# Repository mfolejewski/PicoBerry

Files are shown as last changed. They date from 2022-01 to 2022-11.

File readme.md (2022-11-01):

# PicoBerry - miniature Raspberry Pi CM4 carrier board with full 40-pin GPIO header

## Description

PicoBerry is a tiny Raspberry Pi CM4 carrier board, which has technical specification, as following:
- USB-C for power supply (5VDC/3A),
- full 40-pin GPIO header for connecting HAT boards,
- 2x user LEDs (green/red),
- support only CM4 versions (with eMMC onboard, CM4 Lite are not supported),
- standard ACT/PWR LEDs,
- 2-layer PCB, 20x70mm,
- fully open source project (OSHW).

You can connect to the CM4 module standard HAT boards, such as LCD screens (with SPI or DPI interfaces), audio DAC boards, RS232/485 or CAN interfaces, and many more...

Here you can find:
- \photos: a few pictures of the assembled PCB boards and design
- \manufacturing files: all the production files for ordering PCB and assembly at JLCPCB (Gerber files, Pick & Place, BOM, etc.)
- \source files: source files in KiCad and Altium Designer format

## License

Project published as Open Source Hardware (OSHW) under CERN OHL v1.2 (Open Hardware Licence).



Project has been certified as Open Source Hardware by the Open Source Hardware Association (OSHWA).

UID is: PL000010

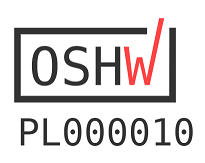
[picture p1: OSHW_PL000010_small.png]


https://certification.oshwa.org/pl000010.html

## Press release:

[Tom's Hardware](https://www.tomshardware.com/news/picoberry-raspberry-pi-4-compute-module-4-carrier-board)

[CNX Software](https://www.cnx-software.com/2022/10/24/miniature-raspberry-pi-cm4-carrier-board-usb-c-port-40-pin-gpio-header)

[NotebookCheck (EN)](https://www.notebookcheck.net/PicoBerry-Raspberry-Pi-Compute-Module-4-carrier-board-arrives-with-40-pin-GPIO-header-and-USB-Type-C-connectivity.664512.0.html)

[NotebookCheck (DE)](https://www.notebookcheck.com/PicoBerry-Besonders-kompaktes-Carrier-Board-fuer-das-Raspberry-Pi-CM4-ist-Open-Source.663859.0.html)

[NotebookCheck (PL)](https://www.notebookcheck.pl/PicoBerry-Raspberry-Plyta-nosna-Pi-Compute-Module-4-przybywa-z-40-pinowym-headerem-GPIO-i-lacznoscia-USB-Type-C.664668.0.html)

[Elektroda.pl (PL)](https://www.elektroda.pl/rtvforum/topic3928796.html)

[LinuxDevices](https://twitter.com/linuxdevices/status/1584419970343395328)

[Tux Machines](http://news.tuxmachines.org/n/2022/10/25/PicoBerry_Carrier_Board_for_the_Raspberry_Pi_CM_4_Build_one_for.shtml)

[Jeff Geerling](https://pipci.jeffgeerling.com/boards_cm/mirkos-picoberry-carrier-board.html)

[hackaday.io](https://hackaday.io/project/182747-picoberry-tiny-cm4-carrier-board)

...and much more:

https://twitter.com/search?q=picoberry&src=typed_query&f=live

https://www.google.com/search?q=picoberry+cm4&oq=picoberry+cm4

## Photos

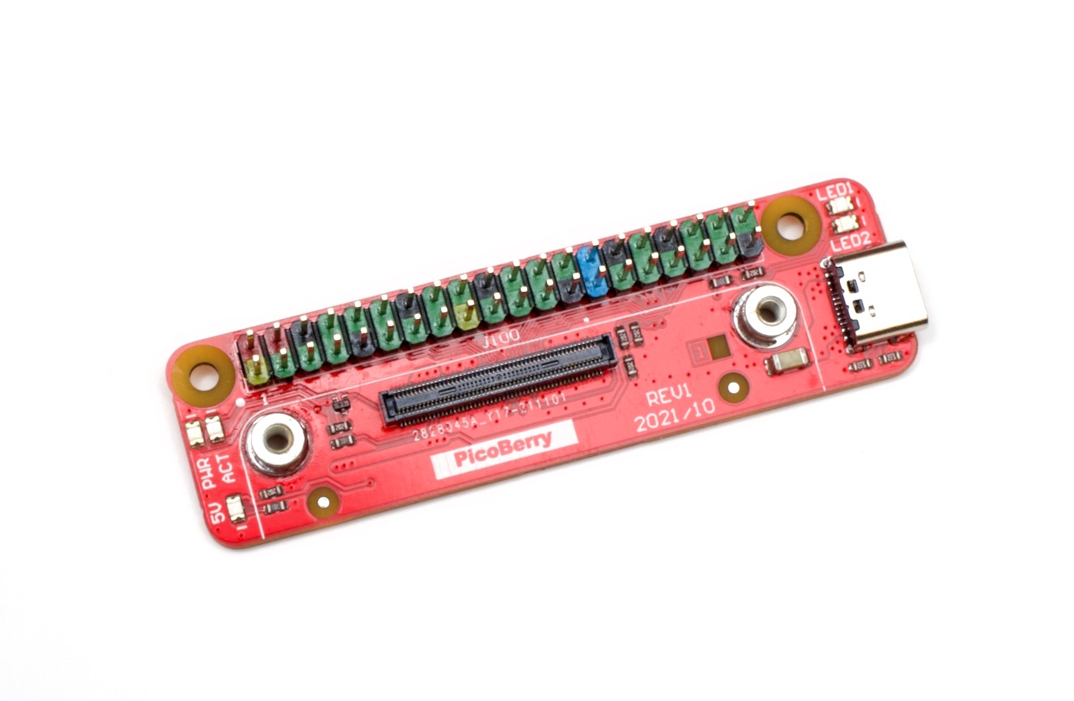
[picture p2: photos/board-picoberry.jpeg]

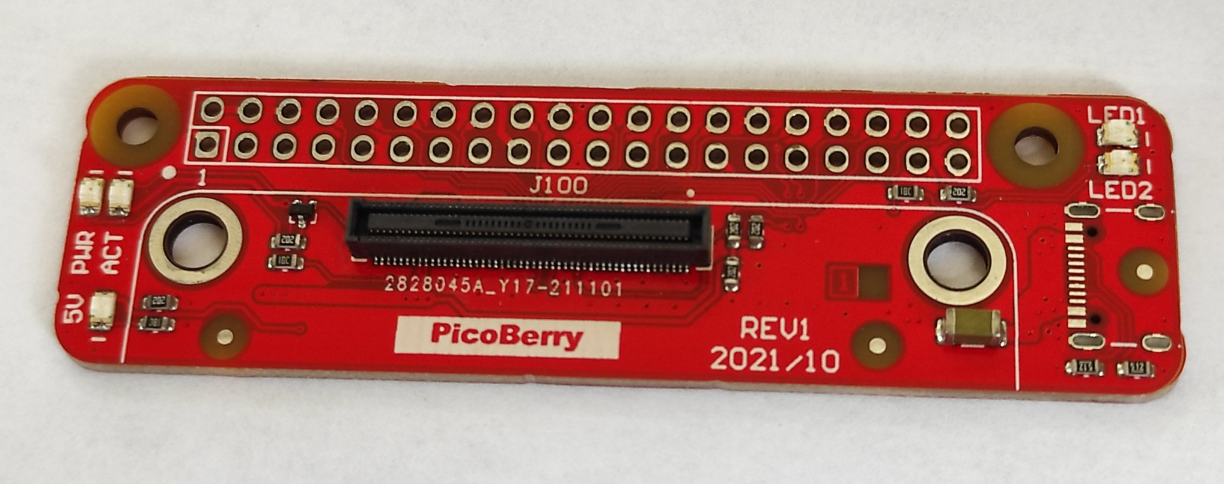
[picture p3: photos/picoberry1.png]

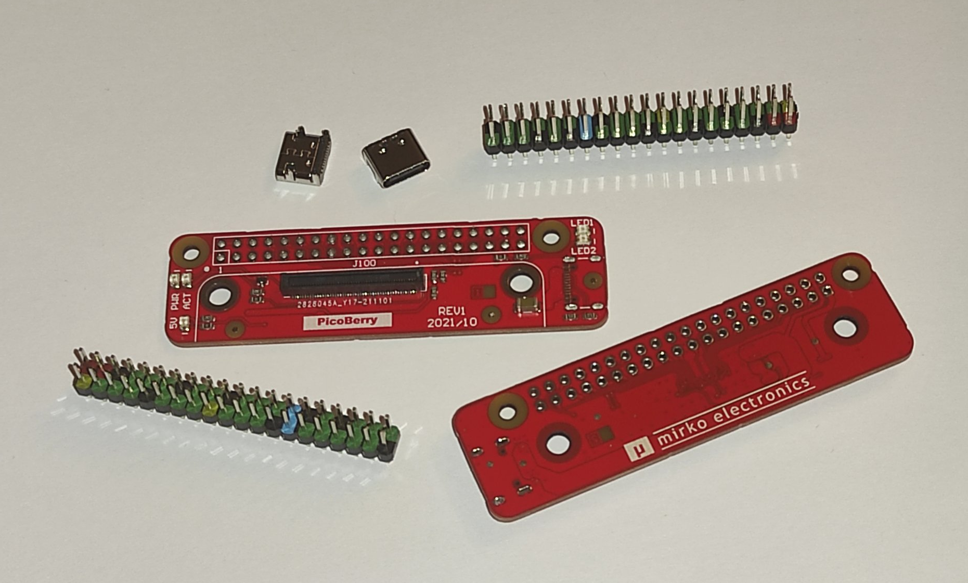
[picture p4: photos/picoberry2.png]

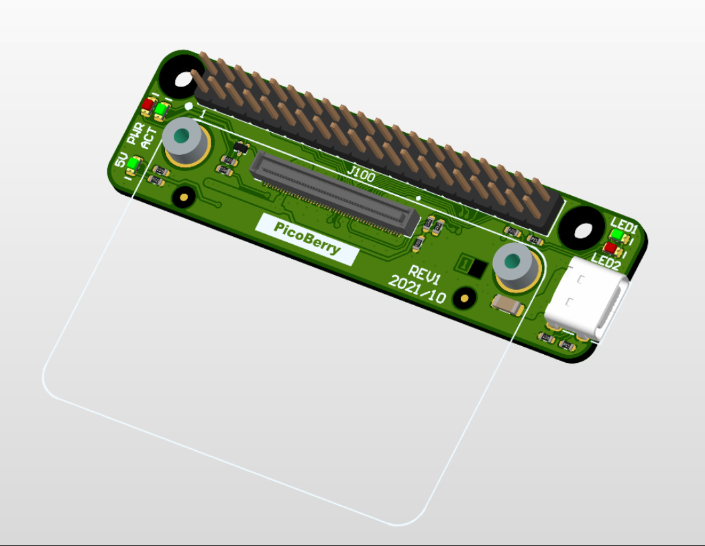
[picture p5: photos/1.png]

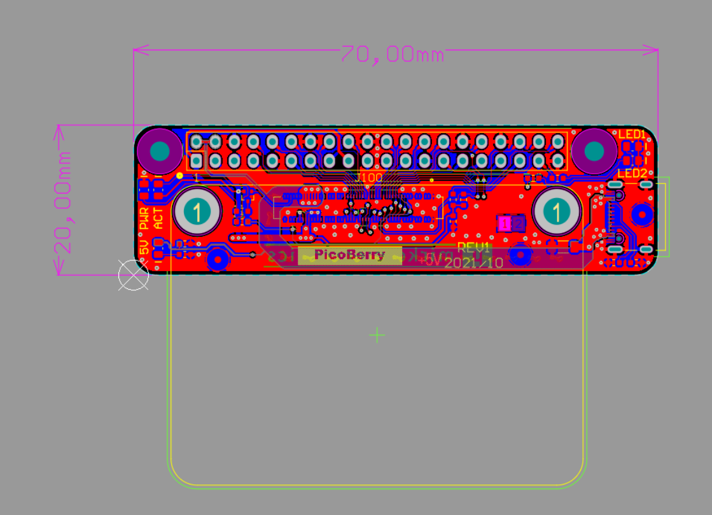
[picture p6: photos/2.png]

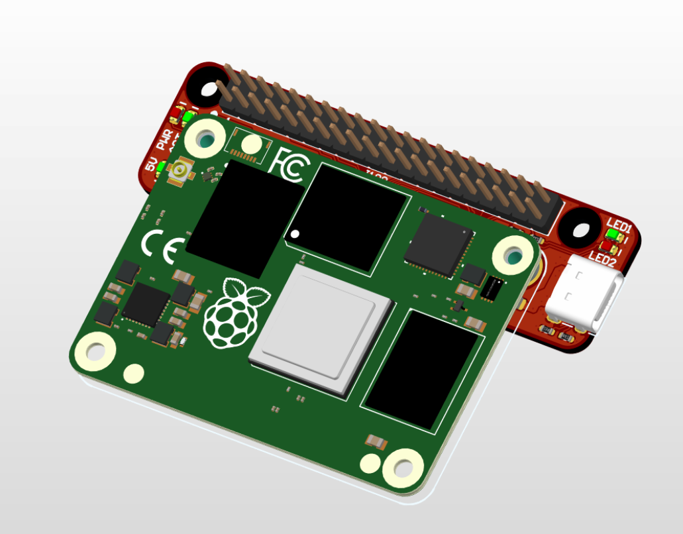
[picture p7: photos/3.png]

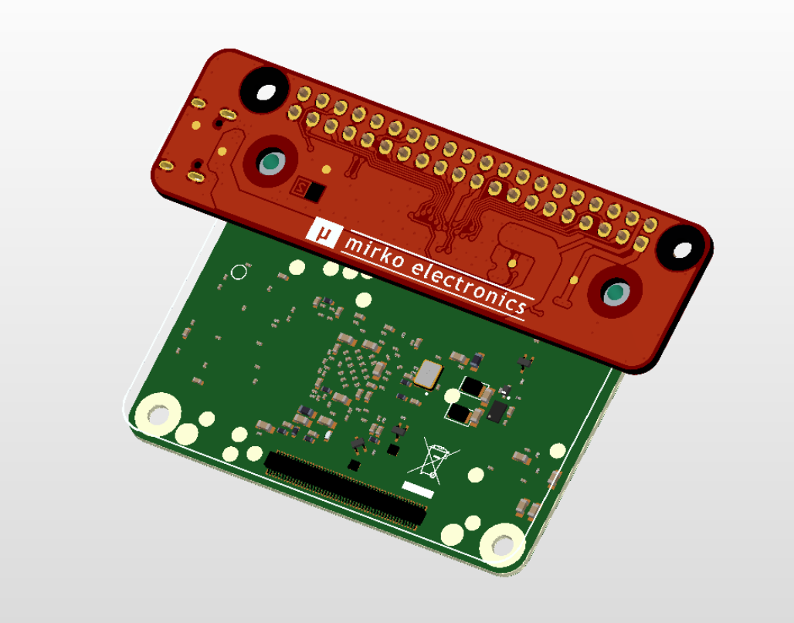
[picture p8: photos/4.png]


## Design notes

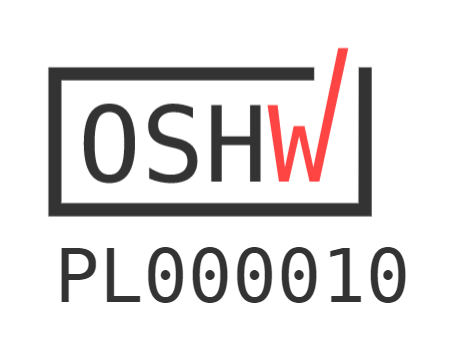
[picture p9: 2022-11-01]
OSHW_PL000010.png

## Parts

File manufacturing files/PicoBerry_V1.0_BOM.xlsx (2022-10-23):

Comment | Designator | Value | Footprint | MPN
100uF/6V3 | C900 | 100uF/6V3 | CAP_1206_R | GENERIC
40pin (2x20pin) | J100 | 40pin (2x20pin) | CON_HDR_P254_2X20M_STR | GENERIC
Mezzanine, 100pin, 3.0mm | J103 | Mezzanine, 100pin, 3.0mm | PCB_BLANK_COMP_SMD | DF40HC(3.0)-100DS-0.4V
U262-161N-4BVC11 | J200 | U262-161N-4BVC11 | CON_XKB_U262-161N-4BVC11 | U262-161N-4BVC11
Red | LED100, LED801 | Red | LED_0805_RED_R | NCD0805R1
Green | LED101, LED800, LED900 | Green | LED_0805_GRN_R | NCD0805G1
M2.5, L = 3.0mm | MECH952, MECH953 | M2.5, L = 3.0mm | PCB_WRT_9774030151 | 977 403 015 1
RPi CM4 Module | MOD100 | RPi CM4 Module | MOD_RPI_CM4_P40_C300_CON1 | CM4 Module
PCB BARE BOARD | PCB1 | PCB BARE BOARD |  | N/A
DTA143ZE | Q902 | DTA143ZE | PKG_SOT523_SC75_SOT416_P100_R | DTA143ZET1G
2k | R101, R102, R105, R107, R805, R907 | 2k | RES_0603_R | TBD
15k | R106, R804, R901 | 15k | RES_0603_R | TBD
5k1 | R201, R203 | 5k1 | RES_0603_R | TBD
M2.5 | SCR950, SCR951 | M2.5 |  | M2.5 screw

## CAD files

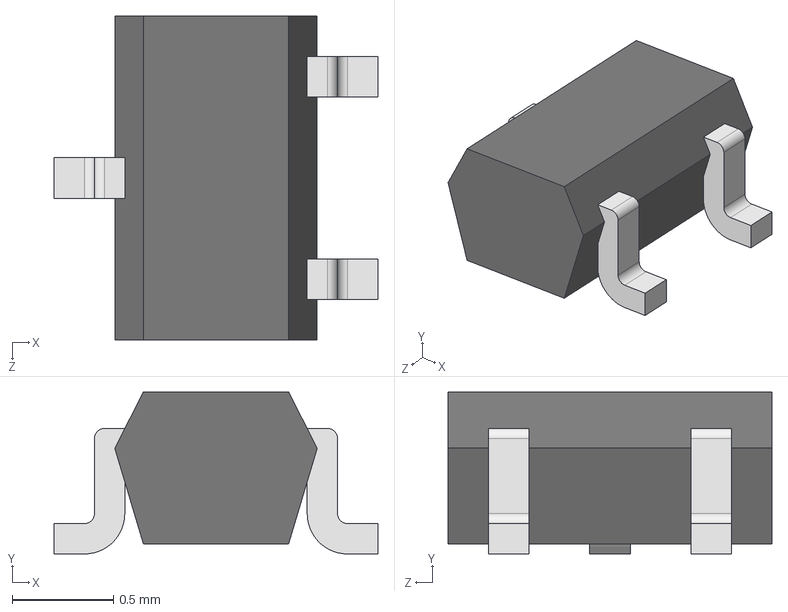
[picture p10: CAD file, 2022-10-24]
source files/KiCad/ALTIUM_EMBEDDED_MODELS/User Library-SOT-416.step
1.60 x 0.8 x 1.60 mm

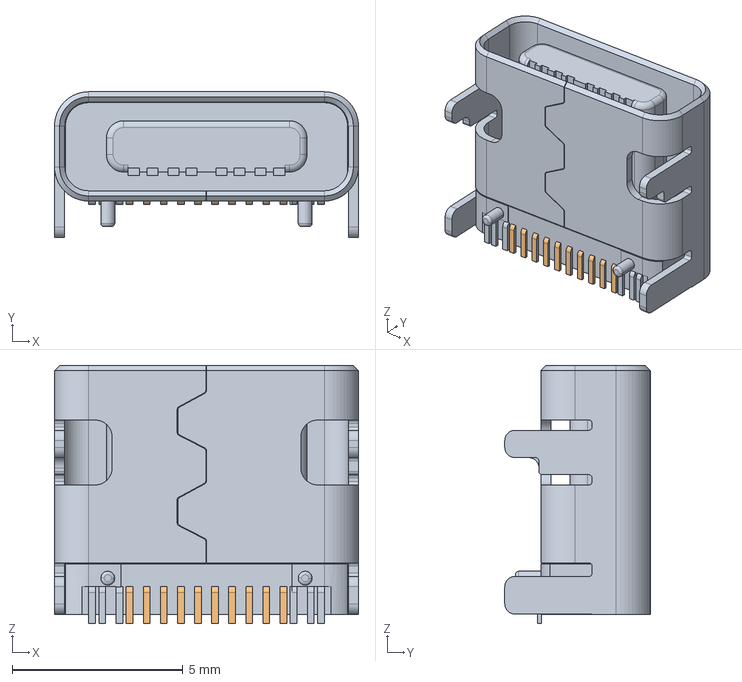
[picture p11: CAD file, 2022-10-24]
source files/KiCad/ALTIUM_EMBEDDED_MODELS/XKB-Connectivity_U262-161N-4BVC11.stp
8.90 x 4.26 x 7.56 mm

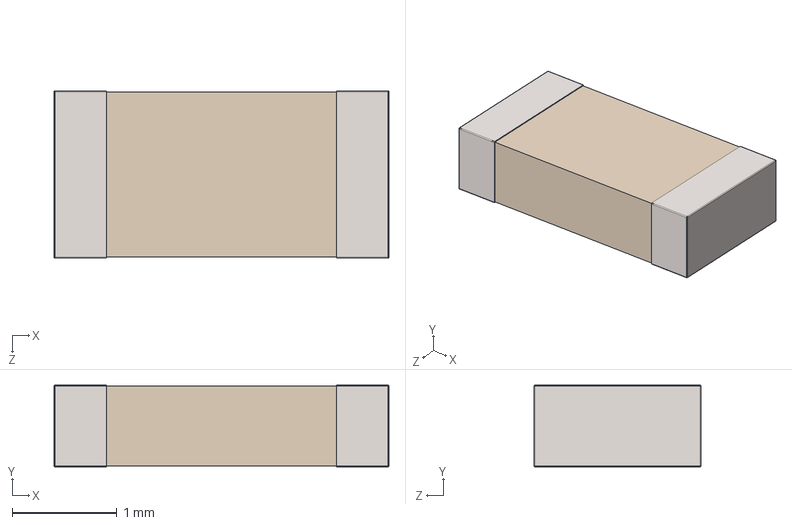
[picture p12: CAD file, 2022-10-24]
source files/KiCad/ALTIUM_EMBEDDED_MODELS/CAP1206.step
3.20 x 0.78 x 1.60 mm

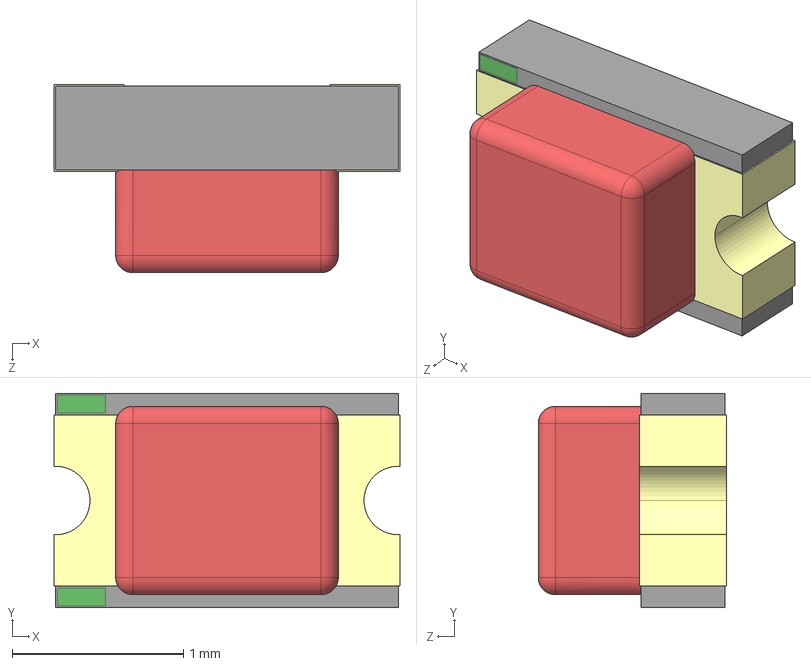
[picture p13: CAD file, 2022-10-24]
source files/KiCad/ALTIUM_EMBEDDED_MODELS/User Library-led_0805.step
2.02 x 1.25 x 1.10 mm

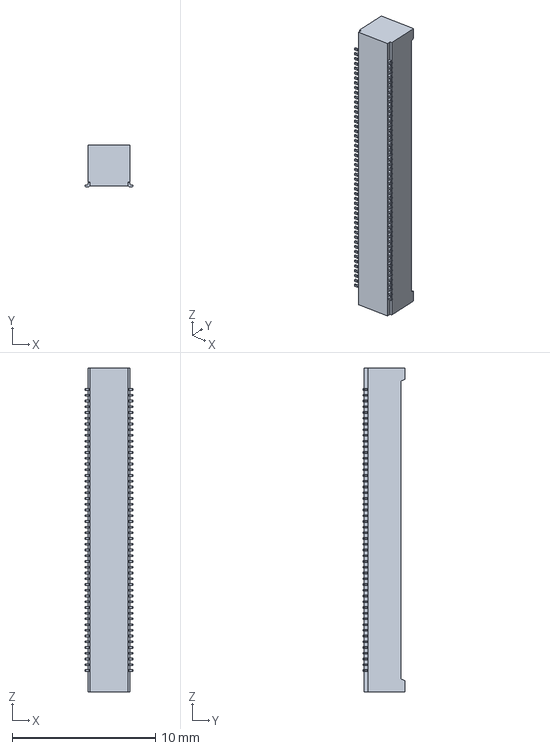
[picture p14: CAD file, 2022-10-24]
source files/KiCad/ALTIUM_EMBEDDED_MODELS/Hirose_DF40HC(3.0)-100DS-0.4V.stp
3.38 x 2.90 x 22.6 mm

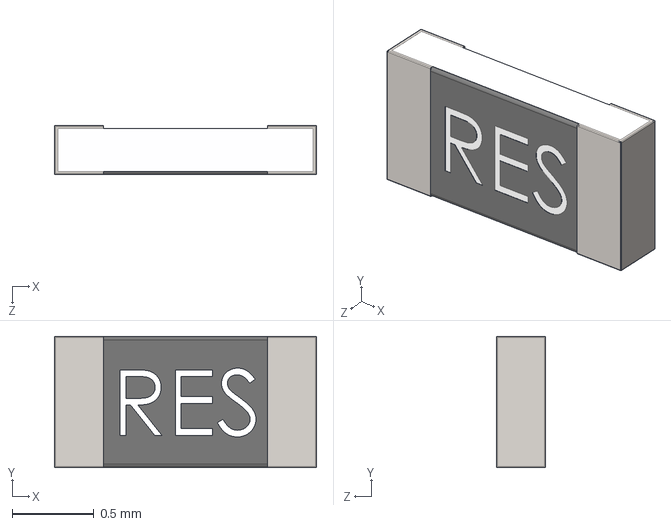
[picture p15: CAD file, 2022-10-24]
source files/KiCad/ALTIUM_EMBEDDED_MODELS/RESC1608X_0603.step
1.60 x 0.8 x 0.3 mm

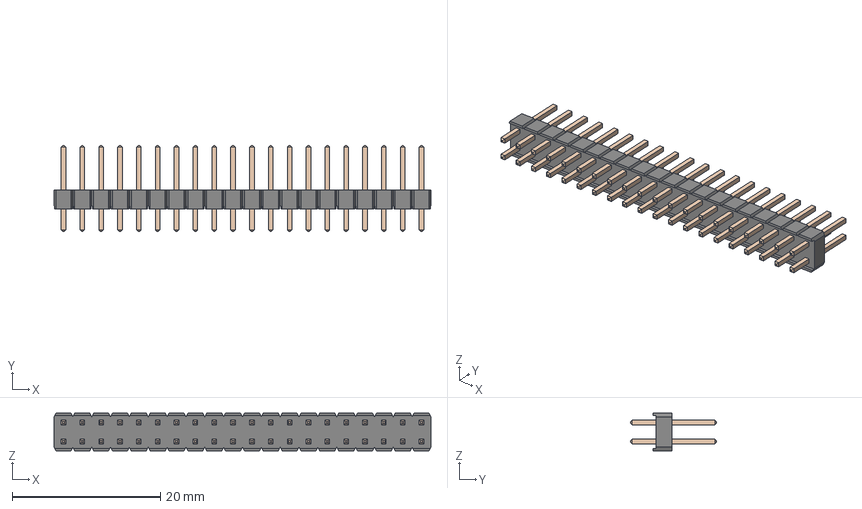
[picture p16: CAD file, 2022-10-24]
source files/KiCad/ALTIUM_EMBEDDED_MODELS/61304021121.stp
50.8 x 11.5 x 5.08 mm
6130xx21121_PIN x 40

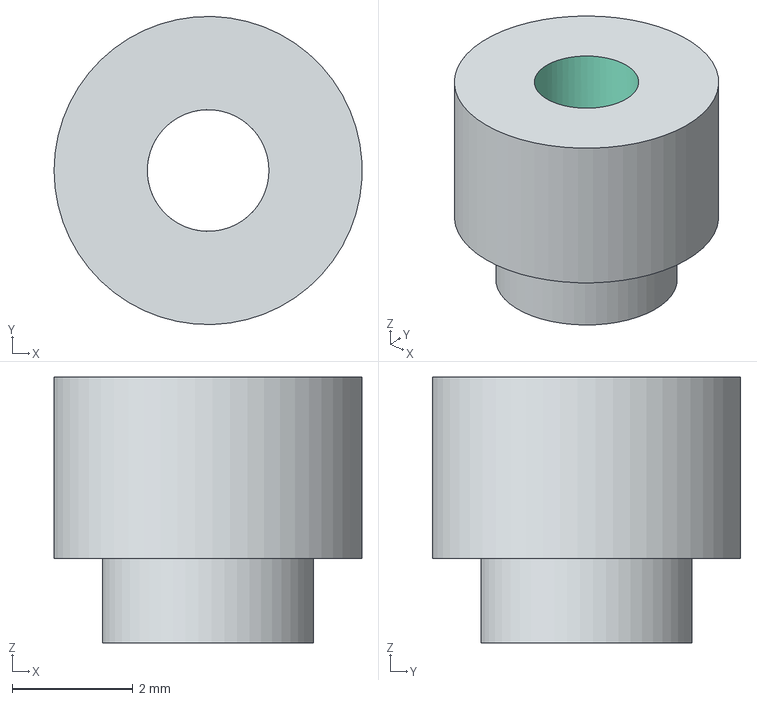
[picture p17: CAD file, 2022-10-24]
source files/KiCad/ALTIUM_EMBEDDED_MODELS/9774030151.stp
5.10 x 5.10 x 4.40 mm

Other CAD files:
source files/KiCad/ALTIUM_EMBEDDED_MODELS/User Library-led_0805G.stp

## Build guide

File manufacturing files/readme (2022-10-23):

manufacturing files: BOM, Pick & Place, CAM Files

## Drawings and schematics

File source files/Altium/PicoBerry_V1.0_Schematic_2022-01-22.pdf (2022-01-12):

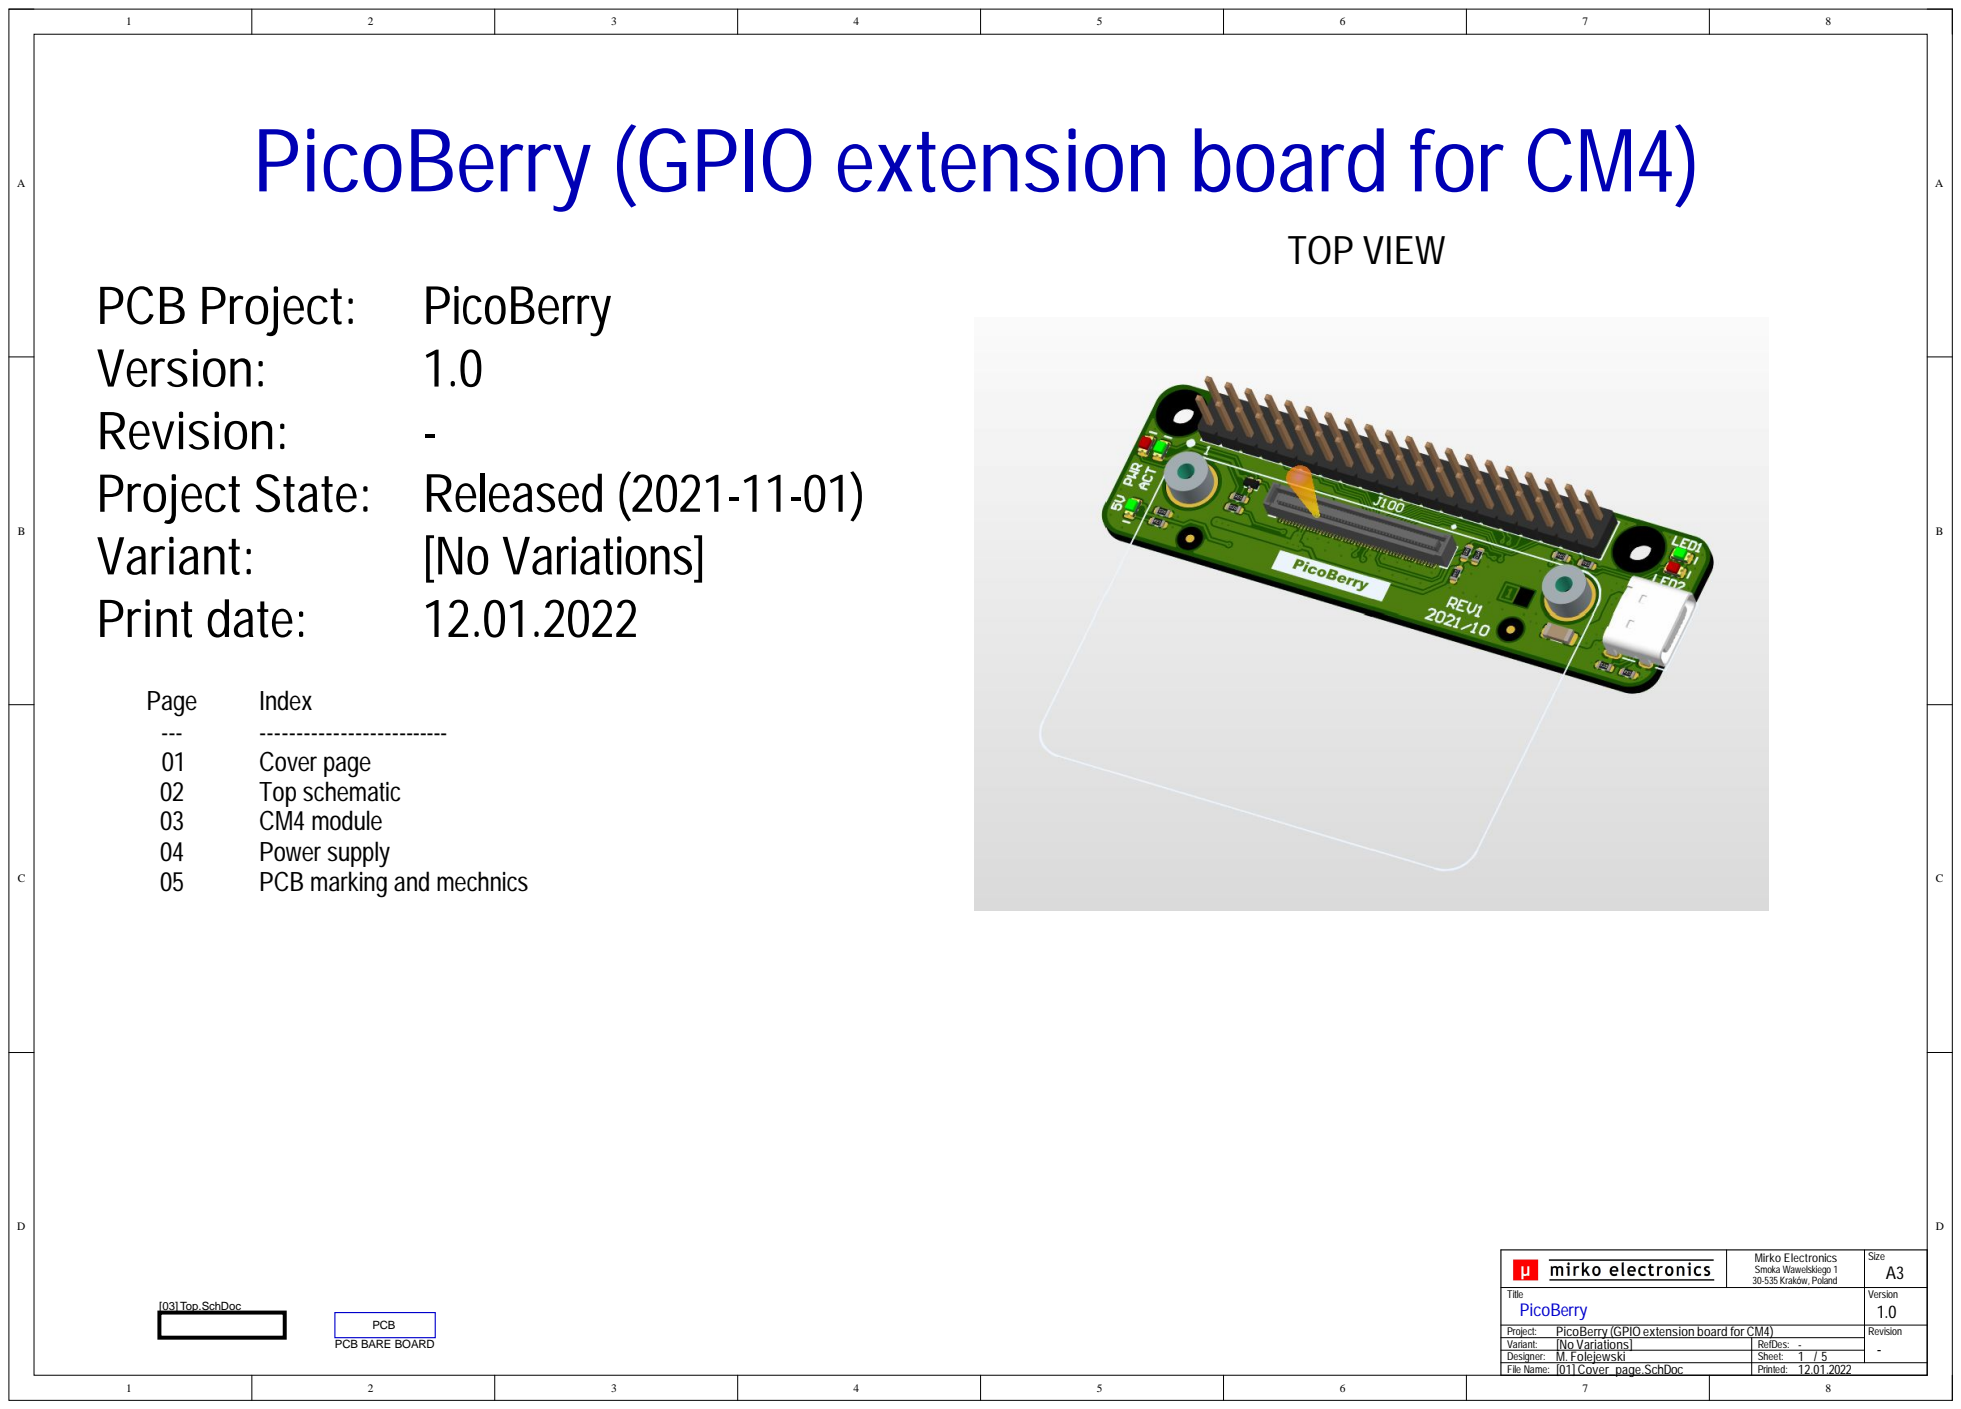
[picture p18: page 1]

Mirko Electronics Smoka Wawelskiego 1 30-535 Kraków, Poland | Size A3

Title PicoBerry | | Version 1.0

Project: PicoBerry (GPIO extension board for CM4) | | Revision -
Variant: [No Variations] | RefDes: -
Designer: M. Folejewski
File Name: [01] Cover_page.SchDoc | Printed:

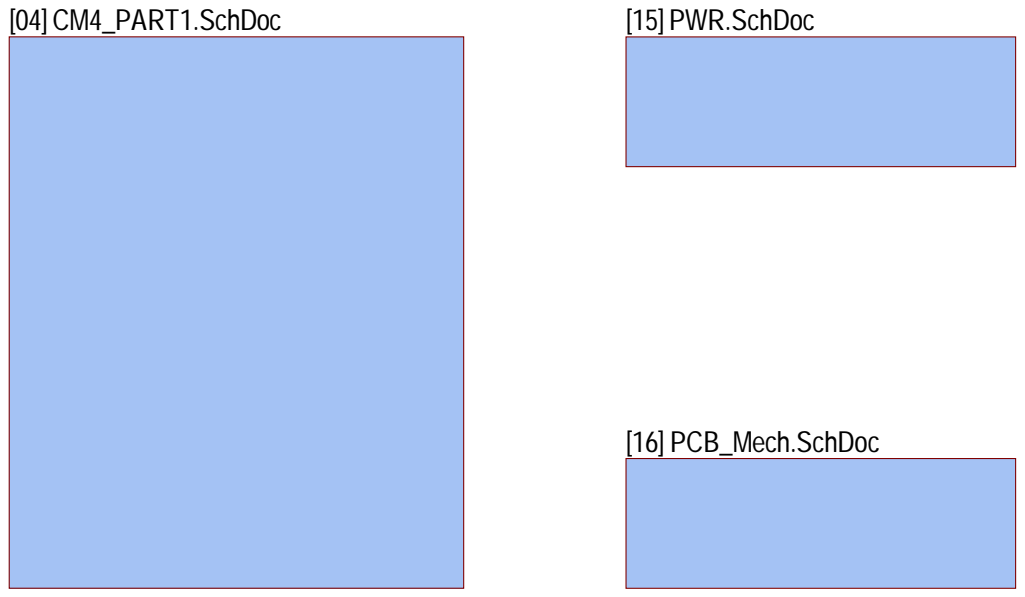
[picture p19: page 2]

Mirko Electronics Smoka Wawelskiego 1 30-535 Kraków, Poland | Size A4

Title Top schematic | | Version 1.0

Project: PicoBerry (GPIOextension board for CM4) | | Revision -
Variant: [No Variations] | RefDes: 1-99

Sheet: 2 5 /

File Name: [03] TOP.SchDoc | Printed: 12.01.2022

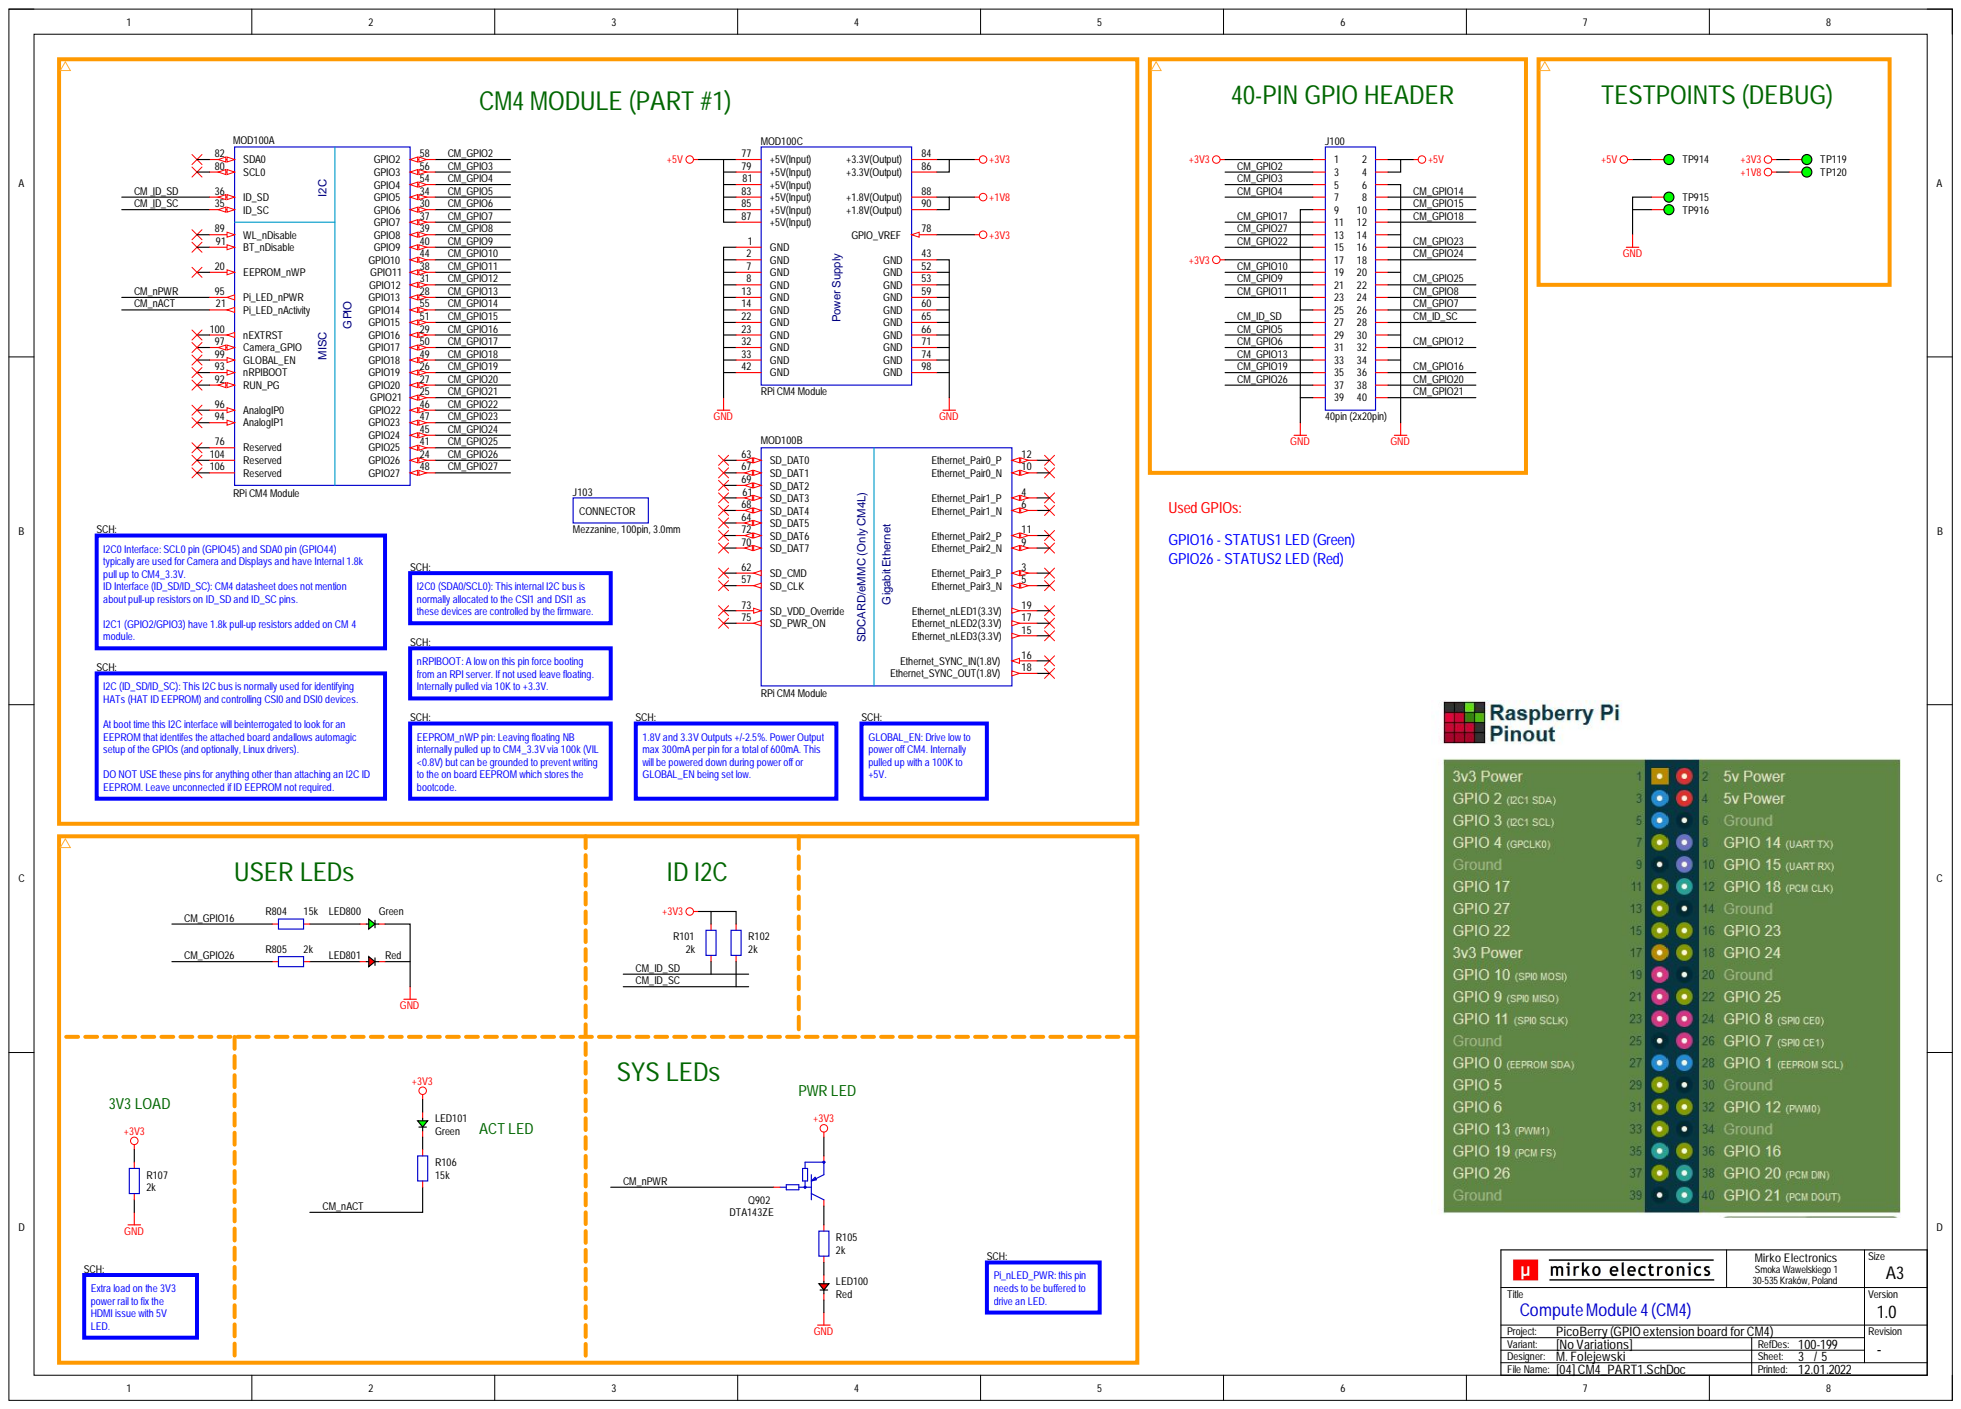
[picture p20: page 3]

85 | 90
87 | 7 8

M4) Mirk o E l ec tro n i cs Smoka Wawelskiego 1 30-535 Kra kó w, Pol a nd | S i z e A 3

T i tl e C o m p u te Mod ule 4 (CM4) | | Versi on 1.0

Proj ect: P i co B e rry (G P I O ex te n s i o n b o a rd fo r C | | R evi s i on -
Vari a n t: [ N o V a ri a ti o n s ] | R efDes : 1 00-1 99
Des i g ner: M. F o l ej ews ki | S hee t: 3 / 5
F i l e N ame : [04] C M4_PA R T 1 . S ch Doc | Pri n ted : 1 2. 01 . 2022

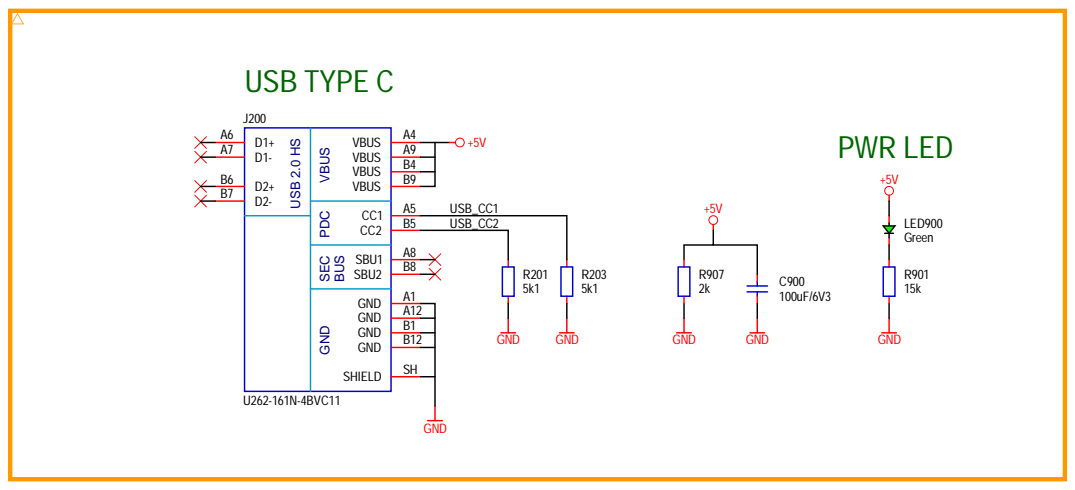
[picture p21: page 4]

GND VBUS PDC SEC

Mirko Electronics Smoka Wawelskiego 1 30-535 Kraków, Poland | Size A4

Title +5V power supply | | Version 1.0

Project: PicoBerry (GPIOextension board for CM4) | | Revision -
Variant: [No Variations] | RefDes: 900-949

File Name: [15] PWR.SchDoc | Printed:

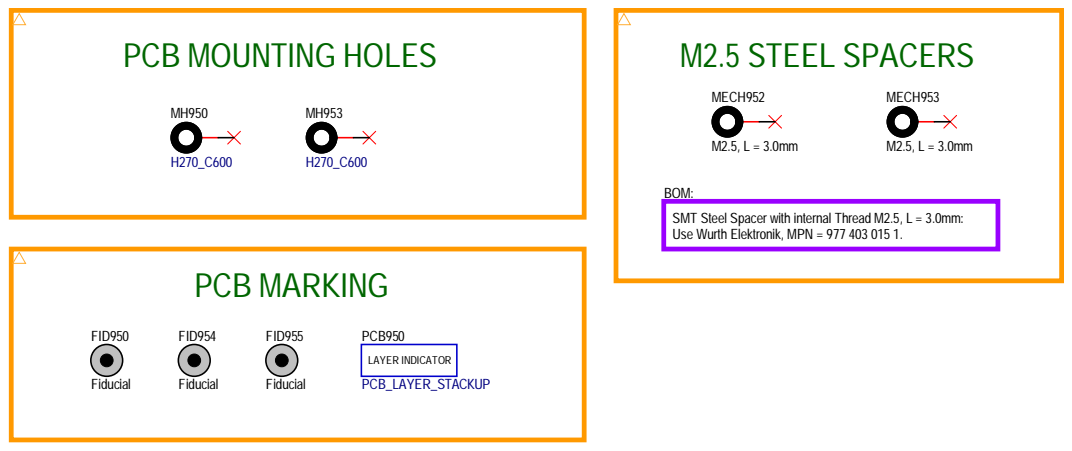
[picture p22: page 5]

BOM:
SMT Steel Spacer with internal Thread M2.5, L = 3.0mm:
Use Wurth Elektronik, MPN = 977 403 015 1.

Mirko Electronics Smoka Wawelskiego 1 30-535 Kraków, Poland | Size A4

Title PCB marking & mechanical parts | | Version 1.0

Project: PicoBerry (GPIOextension board for CM4) | | Revision -
Variant: [No Variations] | RefDes: 950-999

File Name: [16] PCB_Mech.SchDoc | Printed:

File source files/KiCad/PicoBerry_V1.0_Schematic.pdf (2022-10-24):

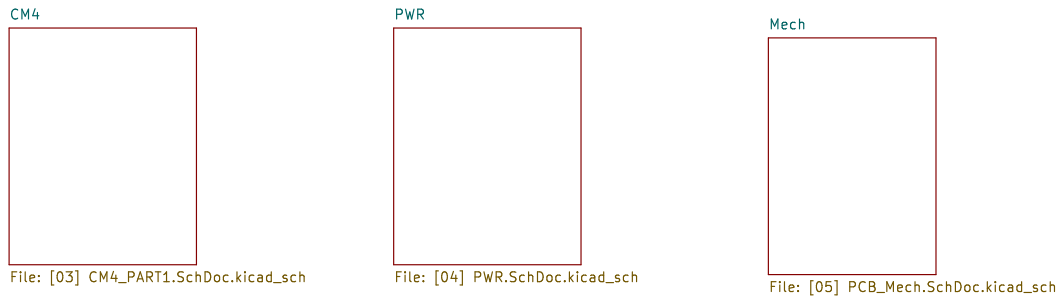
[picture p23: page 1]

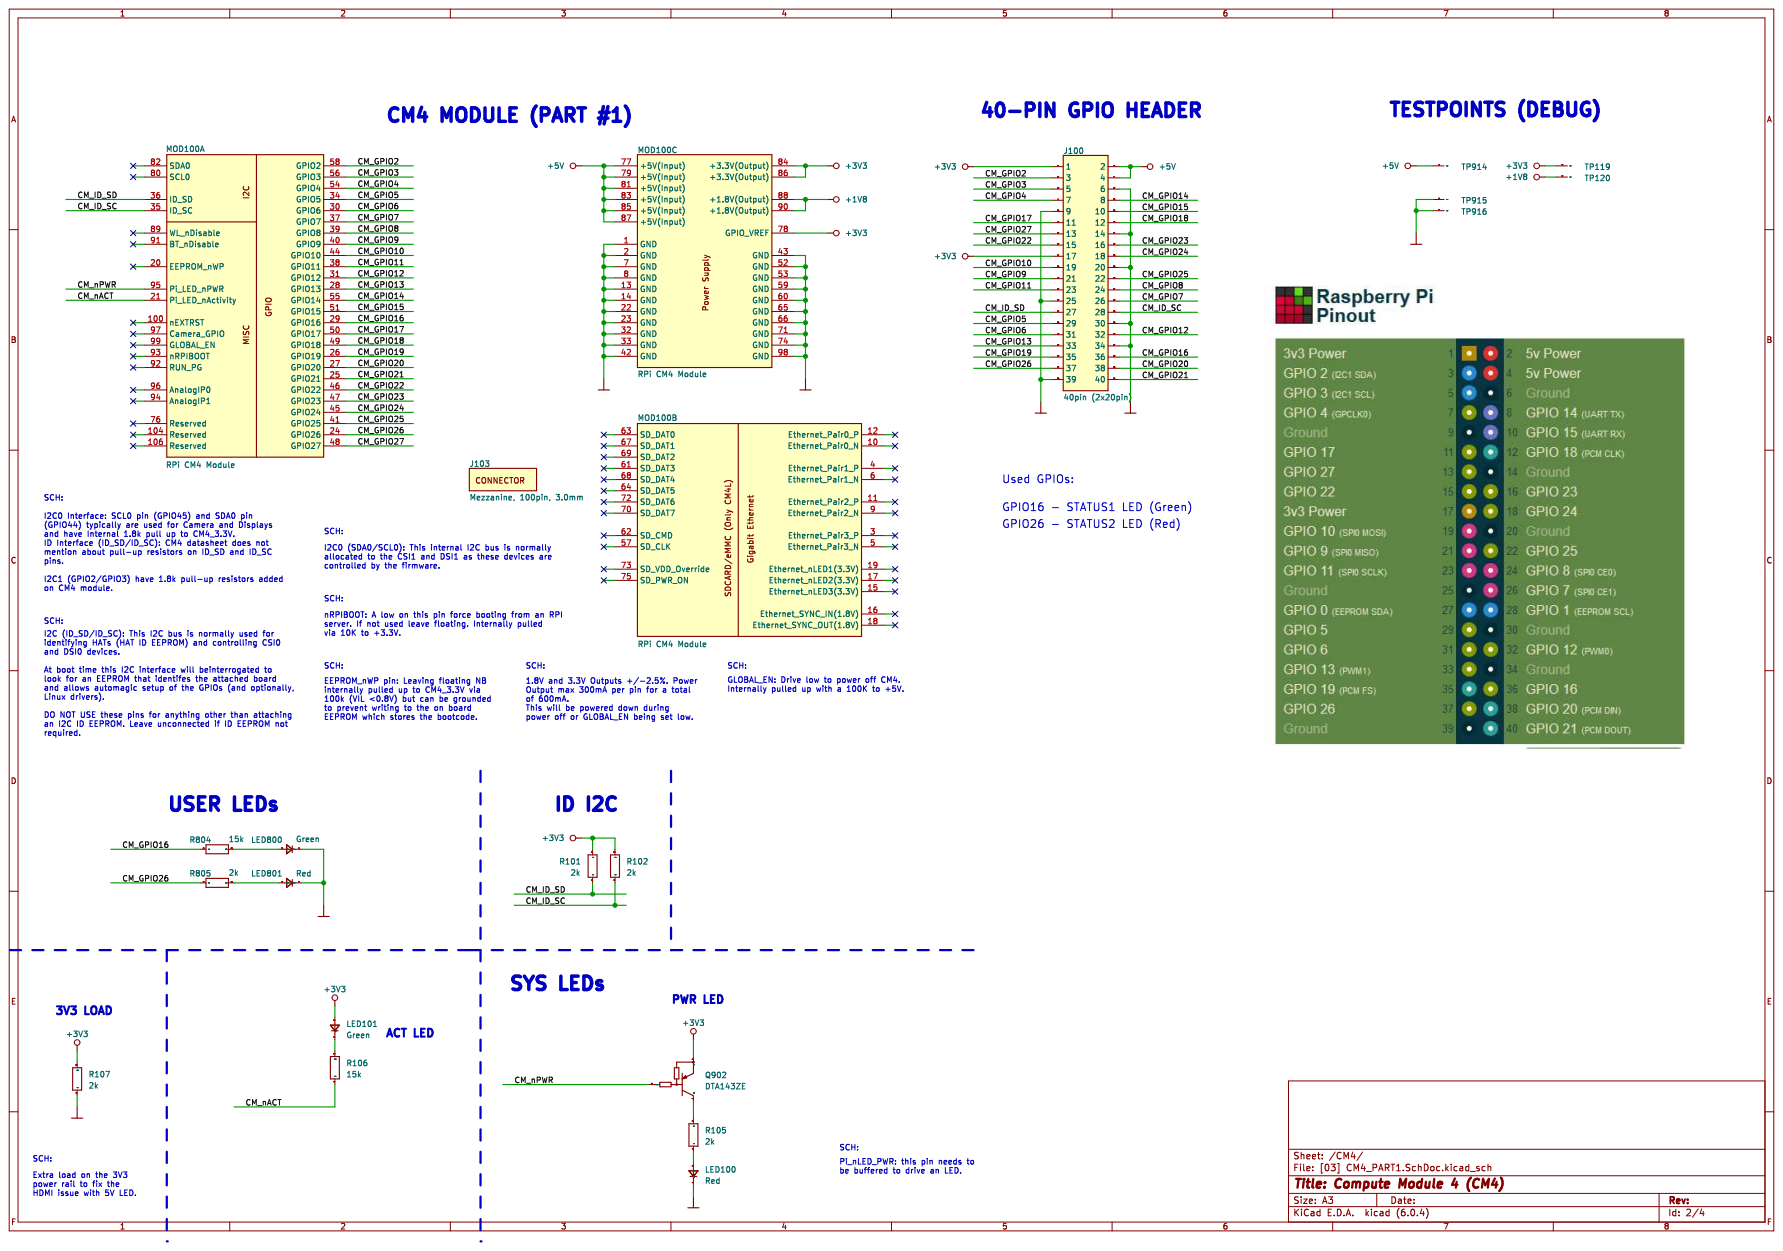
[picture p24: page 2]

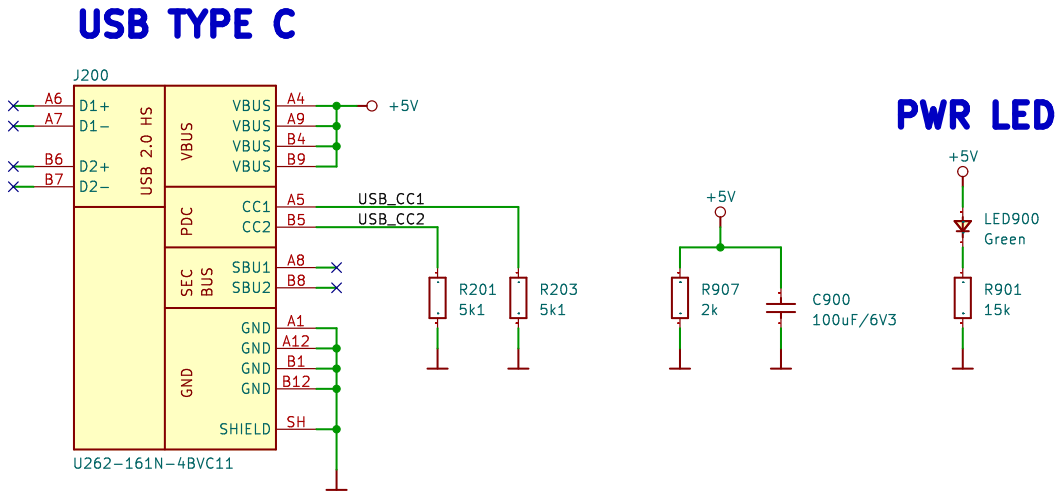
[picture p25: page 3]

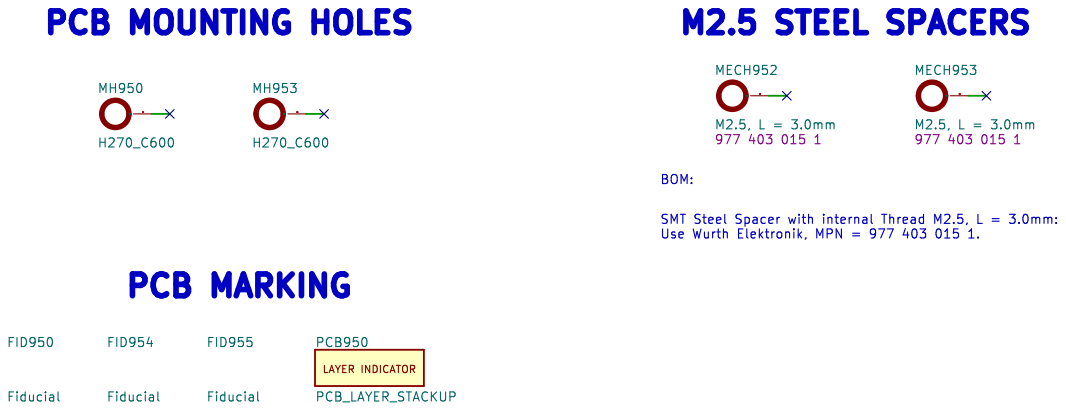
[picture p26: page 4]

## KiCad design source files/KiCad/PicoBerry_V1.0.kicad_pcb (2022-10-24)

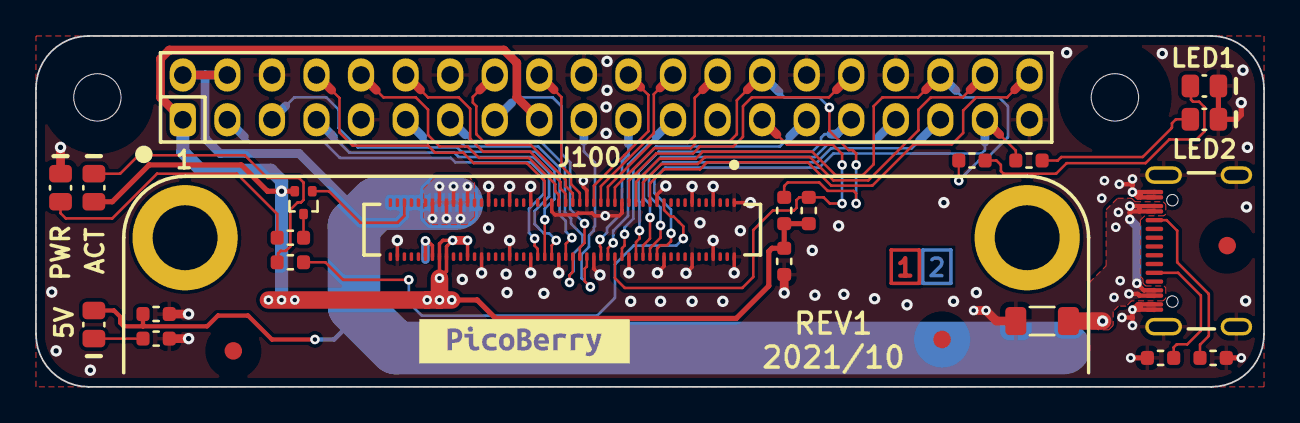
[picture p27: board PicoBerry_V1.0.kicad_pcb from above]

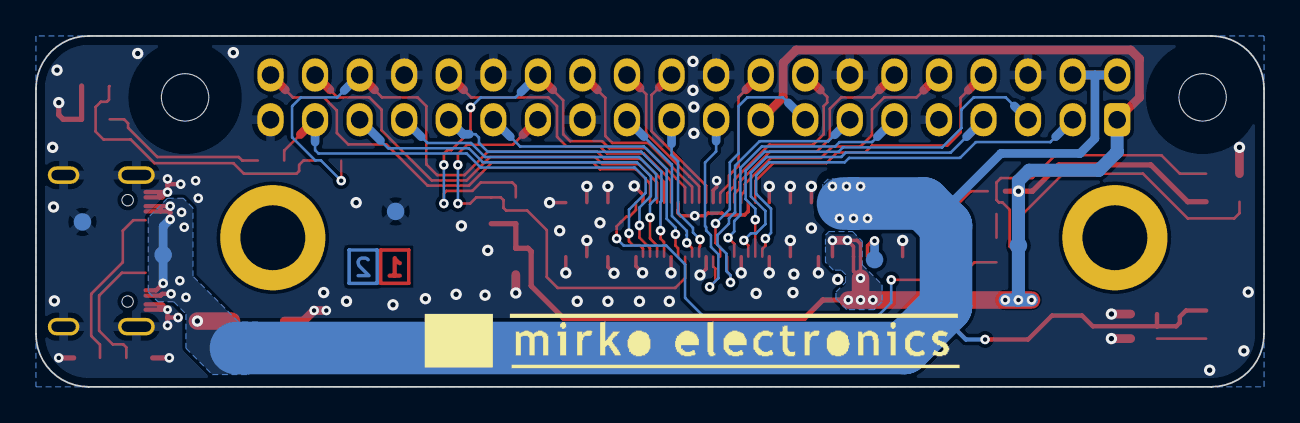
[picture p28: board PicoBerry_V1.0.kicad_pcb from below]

Board: 2 copper layers, 70.0 x 20.0 mm, 36 parts (5 on the bottom side), 42 nets.

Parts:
C900: 100uF/6V3; CAP_1206_R
FID950, FID954, FID955: Fiducial; PCB_FID_RND_100x300
J100: 40pin (2x20pin); CON_HDR_P254_2X20M_STR
J103: Mezzanine, 100pin, 3.0mm; PCB_BLANK_COMP_SMD
J200: U262-161N-4BVC11; _!MirFol_lib_MirFol_lib.PcbLib_CON_XKB_U262-161N-4BVC11
LED100, LED801: Red; LED_0805_RED_R
LED101, LED800, LED900: Green; LED_0805_GRN_R
MECH952, MECH953: M2.5, L = 3.0mm; PCB_WRT_9774030151
MH950, MH953: H270_C600; _2020-11-04_MirFol_lib.PcbLib_PCB_MH_H270_C600
MOD100: RPi CM4 Module; _CM4_PicoBerry_lib_MirFol_lib_Modules.PcbLib_MOD_RPI_CM4_P4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
PCB950: PCB_LAYER_STACKUP; _Biblioteki_MirFol_nowe_Pineberry_Lib.PcbLib_PCB_STACKUP-2L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
Q902: DTA143ZE; PKG_SOT523_SC75_SOT416_P100_R
R101, R102, R107, R805, R907: 2k; RES_0603_R
R105: 2k; _!MirFol_lib_MirFol_db_local.DbLib_RESISTOR$_RES_0603_R
R106: 15k; _!MirFol_lib_MirFol_db_local.DbLib_RESISTOR$_RES_0603_R
R201, R203: 5k1; _!MirFol_lib_MirFol_db_local.DbLib_RESISTOR$_RES_0603_R
R804, R901: 15k; RES_0603_R
TP119, TP120, TP914, TP915, TP916: ICT; PCB_TP_ICT_100
kibuzzard-634662D7: G***; kibuzzard-634662D7

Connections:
+1V8: MOD100.88 (+1.8V(Output)), MOD100.90 (+1.8V(Output)), TP120.1
+3V3: J100.1, J100.17, LED101.2, MOD100.78 (GPIO_VREF), MOD100.84 (+3.3V(Output)), MOD100.86 (+3.3V(Output)), Q902.2 (E), R101.2, R102.2, R107.2, TP119.1
+5V: C900.2, J100.2, J100.4, J200.A4 (VBUS), J200.A9 (VBUS), J200.B4 (VBUS), J200.B9 (VBUS), LED900.2, MOD100.77 (+5V(Input)), MOD100.79 (+5V(Input)), MOD100.81 (+5V(Input)), MOD100.83 (+5V(Input)), MOD100.85 (+5V(Input)), MOD100.87 (+5V(Input)), R907.2, TP914.1
/CM4/CM_GPIO2: J100.3, MOD100.58 (GPIO2)
/CM4/CM_GPIO3: J100.5, MOD100.56 (GPIO3)
/CM4/CM_GPIO4: J100.7, MOD100.54 (GPIO4)
/CM4/CM_GPIO5: J100.29, MOD100.34 (GPIO5)
/CM4/CM_GPIO6: J100.31, MOD100.30 (GPIO6)
/CM4/CM_GPIO7: J100.26, MOD100.37 (GPIO7)
/CM4/CM_GPIO8: J100.24, MOD100.39 (GPIO8)
/CM4/CM_GPIO9: J100.21, MOD100.40 (GPIO9)
/CM4/CM_GPIO10: J100.19, MOD100.44 (GPIO10)
/CM4/CM_GPIO11: J100.23, MOD100.38 (GPIO11)
/CM4/CM_GPIO12: J100.32, MOD100.31 (GPIO12)
/CM4/CM_GPIO13: J100.33, MOD100.28 (GPIO13)
/CM4/CM_GPIO14: J100.8, MOD100.55 (GPIO14)
/CM4/CM_GPIO15: J100.10, MOD100.51 (GPIO15)
/CM4/CM_GPIO16: J100.36, MOD100.29 (GPIO16), R804.1
/CM4/CM_GPIO17: J100.11, MOD100.50 (GPIO17)
/CM4/CM_GPIO18: J100.12, MOD100.49 (GPIO18)
/CM4/CM_GPIO19: J100.35, MOD100.26 (GPIO19)
/CM4/CM_GPIO20: J100.38, MOD100.27 (GPIO20)
/CM4/CM_GPIO21: J100.40, MOD100.25 (GPIO21)
/CM4/CM_GPIO22: J100.15, MOD100.46 (GPIO22)
/CM4/CM_GPIO23: J100.16, MOD100.47 (GPIO23)
/CM4/CM_GPIO24: J100.18, MOD100.45 (GPIO24)
/CM4/CM_GPIO25: J100.22, MOD100.41 (GPIO25)
/CM4/CM_GPIO26: J100.37, MOD100.24 (GPIO26), R805.1
/CM4/CM_GPIO27: J100.13, MOD100.48 (GPIO27)
/CM4/CM_ID_SC: J100.28, MOD100.35 (ID_SC), R102.1
/CM4/CM_ID_SD: J100.27, MOD100.36 (ID_SD), R101.1
/CM4/CM_nACT: MOD100.21 (Pi_LED_nActivity), R106.1
/CM4/CM_nPWR: MOD100.95 (Pi_LED_nPWR), Q902.1 (B)
/PWR/USB_CC1: J200.A5 (CC1), R203.1
/PWR/USB_CC2: J200.B5 (CC2), R201.1
GND: C900.1, J100.6, J100.9, J100.14, J100.20, J100.25, J100.30, J100.34, J100.39, J200.A1 (GND), J200.A12 (GND), J200.B1 (GND), J200.B12 (GND), J200.SH (SHIELD), LED100.1, LED800.1, LED801.1, MOD100.1 (GND), MOD100.2 (GND), MOD100.7 (GND), MOD100.8 (GND), MOD100.13 (GND), MOD100.14 (GND), MOD100.22 (GND), MOD100.23 (GND), MOD100.32 (GND), MOD100.33 (GND), MOD100.42 (GND), MOD100.43 (GND), MOD100.52 (GND), MOD100.53 (GND), MOD100.59 (GND), MOD100.60 (GND), MOD100.65 (GND), MOD100.66 (GND), MOD100.71 (GND), MOD100.74 (GND), MOD100.98 (GND), R107.1, R201.2, R203.2, R901.2, R907.1, TP915.1, TP916.1
unnamed: LED100.2, R105.1
unnamed: LED101.1, R106.2
unnamed: LED800.2, R804.2
unnamed: LED801.2, R805.2
unnamed: LED900.1, R901.1
unnamed: Q902.3 (C), R105.2
